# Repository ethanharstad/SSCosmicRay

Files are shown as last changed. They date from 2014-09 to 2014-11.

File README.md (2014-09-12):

SSCosmicRay
===========
[Hackaday Project Log](http://hackaday.io/project/2998-Solid-State-Cosmic-Ray-Detector)

Cosmic ray detectors are a common physics experiment and frequently flown on balloons to measure the change in cosmic ray flux with altitude.
These experiments are typically performed with off the shelf Geiger–Müller tube based detectors. G-M tubes are typically quite expensive and involve high voltages which can become difficult to manage in the near vacuum experienced with high altitude balloons.
A reverse biased photodiode can be used in much the same way as a G-M tube but with lower cost, lower voltage, almost no dead time, and the additional benefit of an output voltage proportional to the radiation energy. 

Inspired by a Maxim [application note](http://www.maximintegrated.com/en/app-notes/index.mvp/id/2236).

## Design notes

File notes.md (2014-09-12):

# VBPW34FAS(R) Specs
- Active Area: 7.5 mm2
- Filter Passband: 775 to 1050 nm
- 3 db Half Angle: 65 deg
- Breakdown Voltage (V_{BR}): 60 V
- Reverse Dark Current (I_{RD}): 2 nA @ V_R = 10 V
- Diode Capacitance (C_D): 16 pF @ V_R = 10 V
- Active Surface Standoff:
	- VBPW34FAS - 0.73 to 0.83 mm
	- VBPW34FASR - >0.57 mm

# Solid Angle Calculation
1. Detector Area: A_D = 7.5 mm2
2. Detector Side Length: s_D = sqrt(A_D) = 2.74 mm
3. Effective Radius = r_E / 2 = 1.37 mm
4. Effective Area = A_E = pi * (r_E)^2 = 5.9 mm2
5. Radius to Detector = 0.5 * t_PCB + h_AE = 0.8 mm + .57 mm = 1.37 mm
6. Hemisphere Area = A_H = 2 * pi * r^2 = 11.79 mm2
7. Solid Half Angle = A_E / A_H = 50%

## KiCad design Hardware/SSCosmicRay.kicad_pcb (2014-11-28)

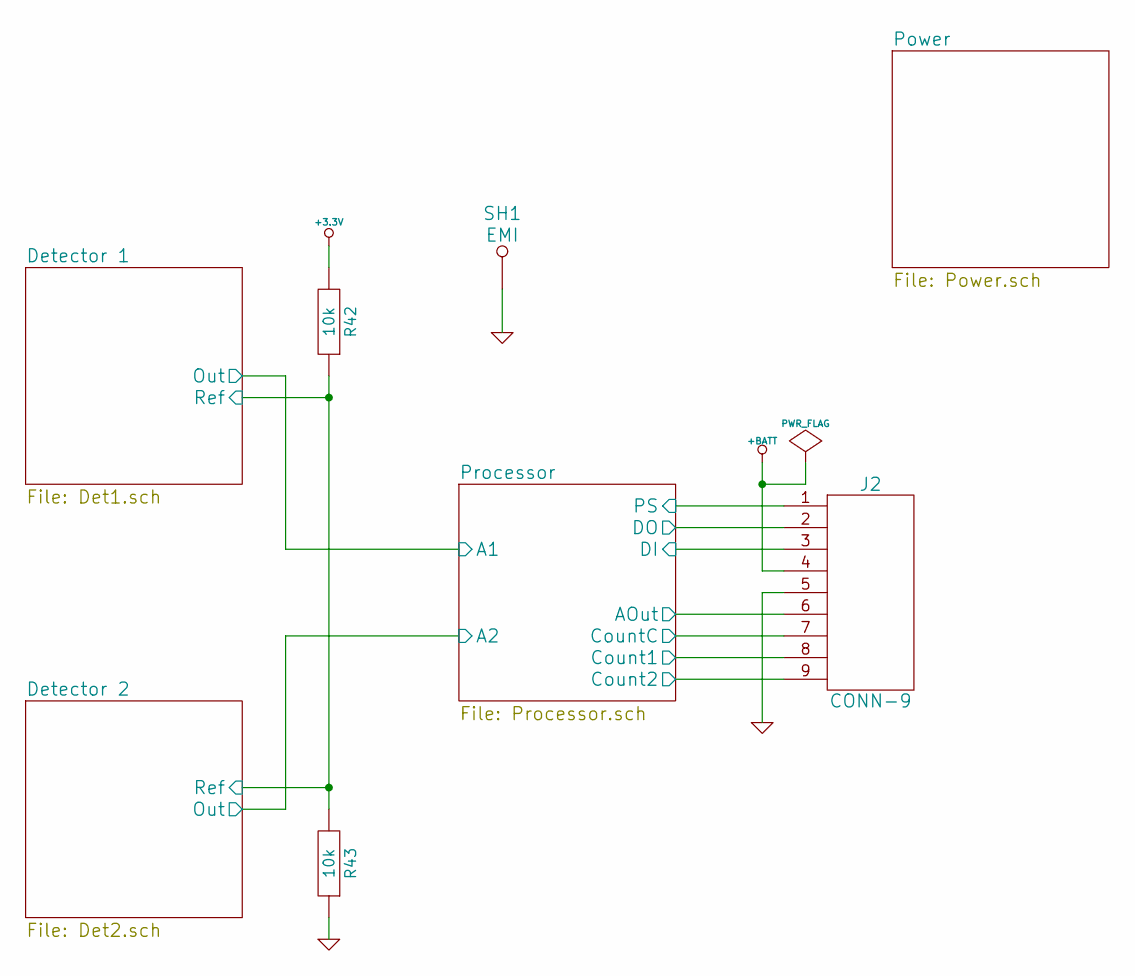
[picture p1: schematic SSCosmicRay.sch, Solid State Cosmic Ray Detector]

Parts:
J2: CONN-9; MFR Part No 1734354-2
R42, R43: 10k; RESC1608; Tolerance 1%; MFR Part No RC0603FR-0710KL
SH1: EMI

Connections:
+3.3V: R42.2; also elsewhere on the board
+BATT: J2.4; also elsewhere on the board
/Detector 1/Ref: R42.1, R43.2; also elsewhere on the board
/Processor/AOut: J2.6; also elsewhere on the board
/Processor/Count1: J2.8; also elsewhere on the board
/Processor/Count2: J2.9; also elsewhere on the board
/Processor/CountC: J2.7; also elsewhere on the board
/Processor/DI: J2.3; also elsewhere on the board
/Processor/DO: J2.2; also elsewhere on the board
/Processor/PS: J2.1; also elsewhere on the board
GND: J2.5, R43.1, SH1.1; also elsewhere on the board

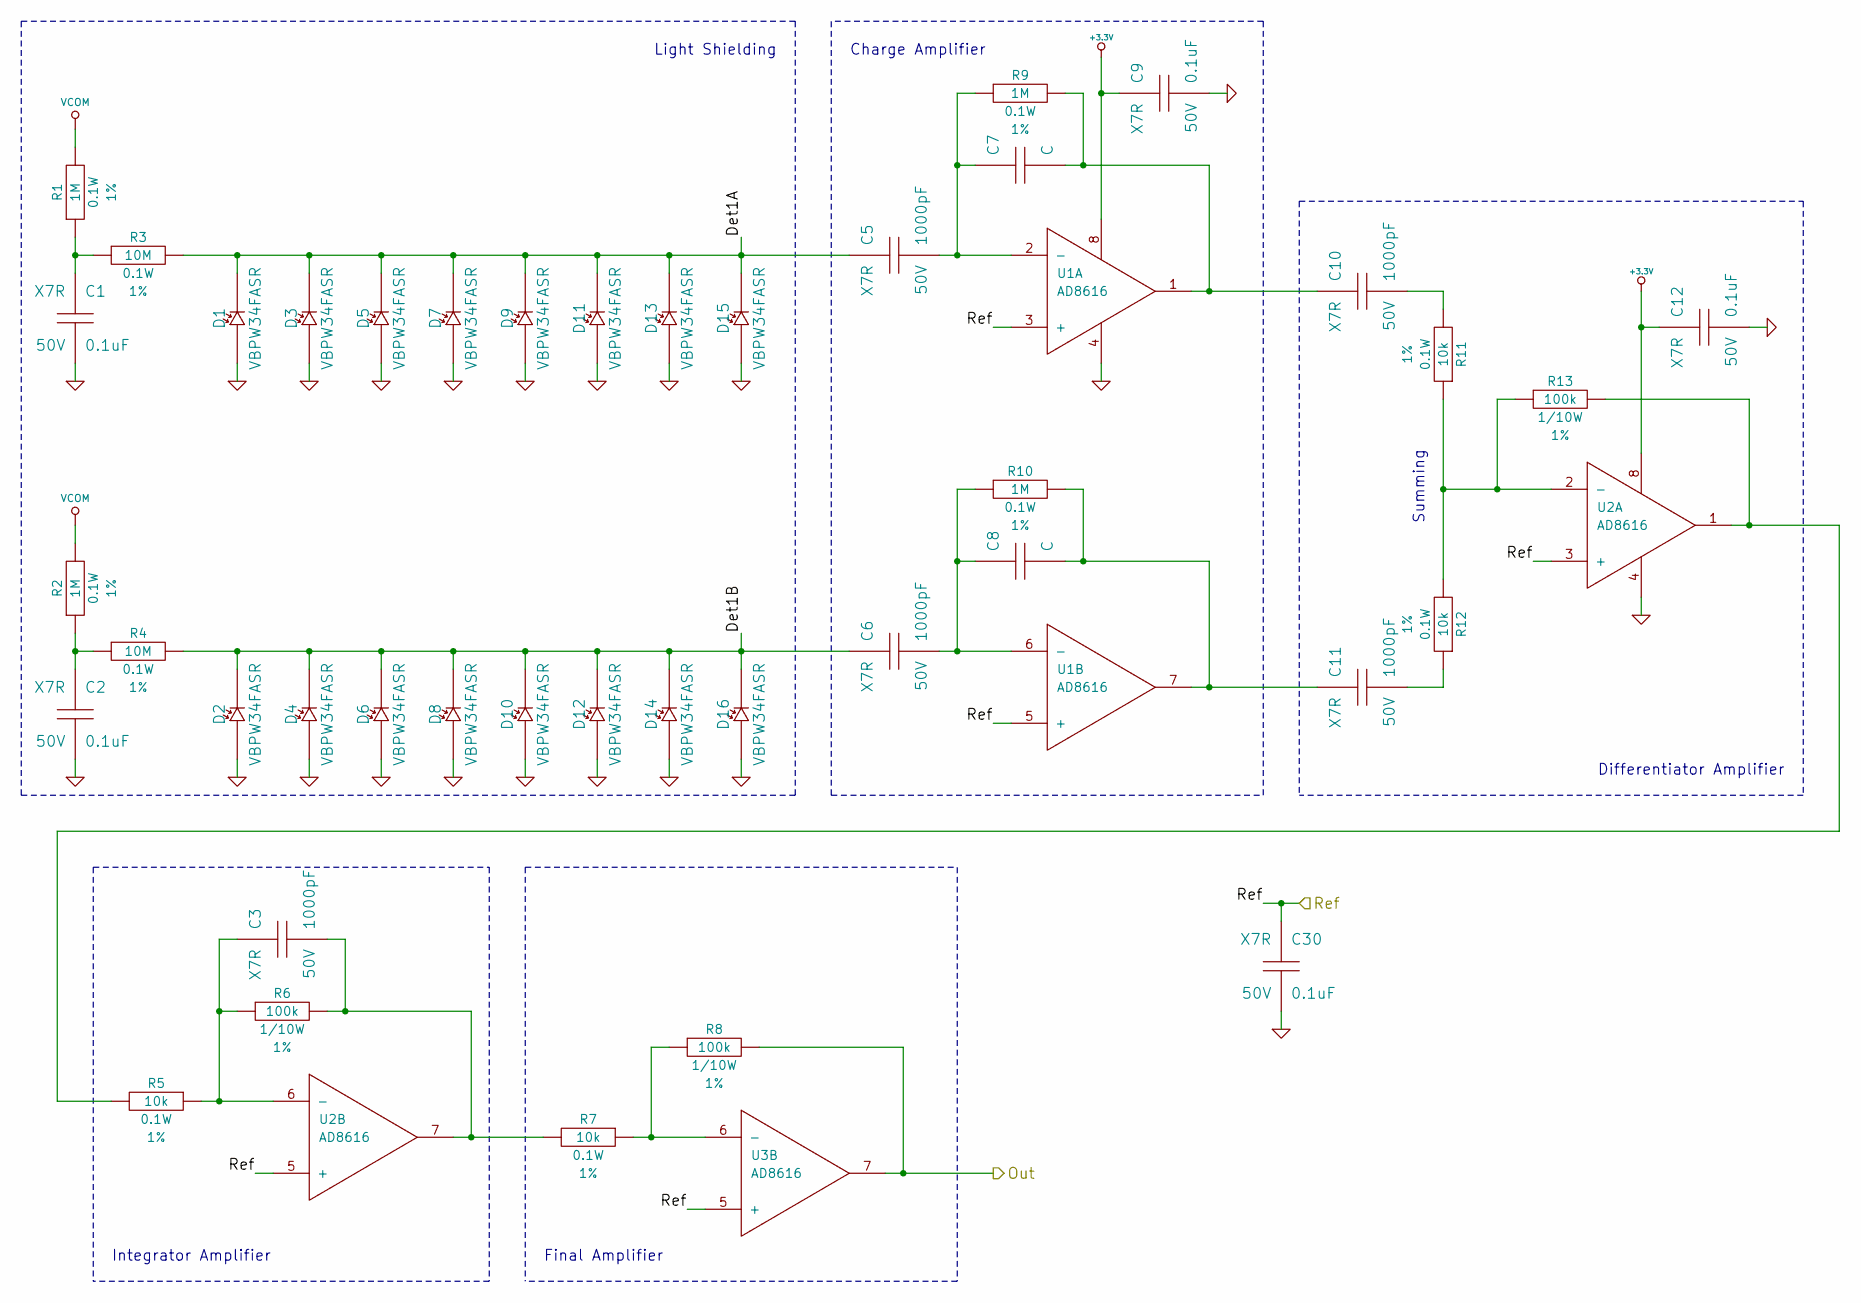
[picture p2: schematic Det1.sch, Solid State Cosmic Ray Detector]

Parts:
C1, C2, C9, C12, C30: 0.1uF; CAPC1608; Voltage 50V; MFR Part No CL10B104KB8SFNC
C3, C5, C6, C10, C11: 1000pF; CAPC1608; Voltage 50V; MFR Part No CL10B102KB8SFNC
C7, C8: C; Voltage V
D1, D2, D3, D4, D5, D6, D7, D8, D9, D10, D11, D12, D13, D14, D15, D16: VBPW34FASR; DIOC-BPW34R; MFR Part No VBPW34FASR
R1, R2, R9, R10: 1M; RESC1608; Tolerance 1%; MFR Part No RC0603FR-071ML
R3, R4: 10M; RESC1608; Tolerance 1%; MFR Part No RC0603FR-0710ML
R5, R7, R11, R12: 10k; RESC1608; Tolerance 1%; MFR Part No RC0603FR-0710KL
R6, R8, R13: 100k; Tolerance 1%; MFR Part No RC0603FR-07100KL
U1, U2, U3: AD8616; MFR Part No AD8616ARMZ-REEL

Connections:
+3.3V: C9.1, C12.1, U1.8, U2.8; also elsewhere on the board
/Detector 1/Det1A: C5.1, D1.2, D3.2, D5.2, D7.2, D9.2, D11.2, D13.2, D15.2, R3.2
/Detector 1/Det1B: C6.1, D2.2, D4.2, D6.2, D8.2, D10.2, D12.2, D14.2, D16.2, R4.2
/Detector 1/Ref: C30.1, U1.3 (+), U1.5 (+), U2.3 (+), U2.5 (+), U3.5 (+); also elsewhere on the board
/Processor/A1: R8.2, U3.7; also elsewhere on the board
GND: C1.2, C2.2, C9.2, C12.2, C30.2, D1.1, D2.1, D3.1, D4.1, D5.1, D6.1, D7.1, D8.1, D9.1, D10.1, D11.1, D12.1, D13.1, D14.1, D15.1, D16.1, U1.4, U2.4; also elsewhere on the board
unnamed: C8.2, C11.1, R10.2, U1.7
unnamed: C11.2, R12.1
unnamed: C10.2, R11.2
unnamed: C3.2, R6.2, R7.2, U2.7
unnamed: C7.2, C10.1, R9.2, U1.1
unnamed: R11.1, R12.2, R13.1, U2.2 (-)
unnamed: R7.1, R8.1, U3.6 (-)
unnamed: C3.1, R5.1, R6.1, U2.6 (-)
unnamed: R5.2, R13.2, U2.1
unnamed: C6.2, C8.1, R10.1, U1.6 (-)
unnamed: C5.2, C7.1, R9.1, U1.2 (-)
unnamed: C2.1, R2.1, R4.1
unnamed: C1.1, R1.1, R3.1
VCOM: R1.2, R2.2; also elsewhere on the board

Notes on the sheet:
Charge Amplifier
Differentiator Amplifier
Integrator Amplifier
Summing
Light Shielding
Final Amplifier

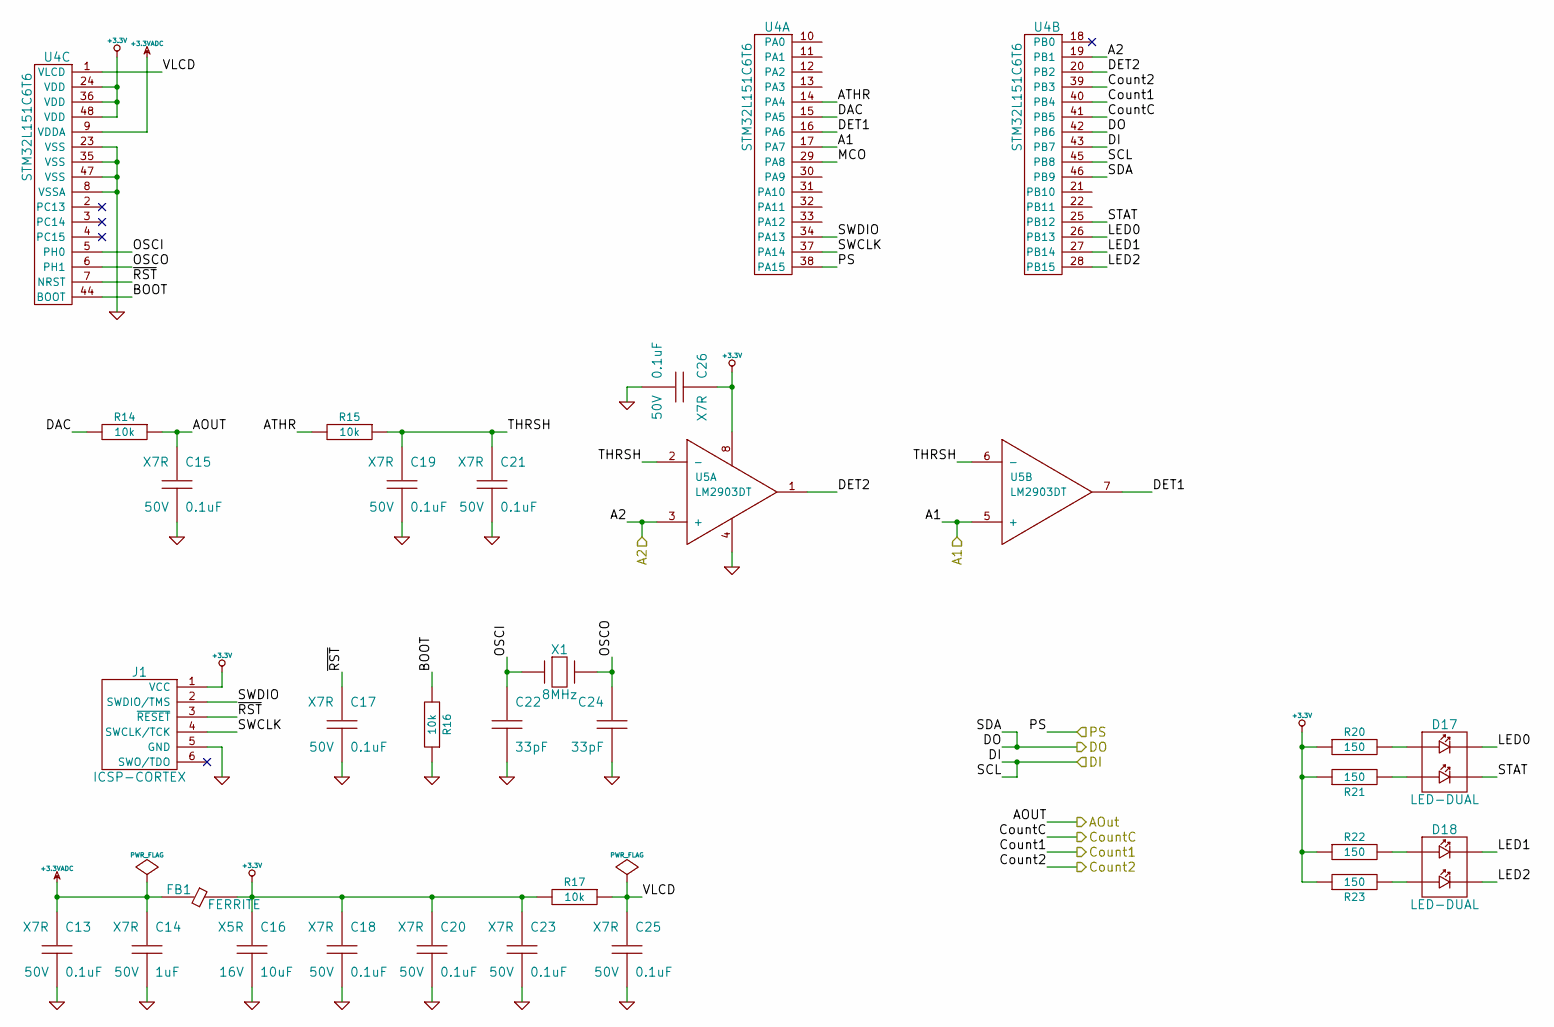
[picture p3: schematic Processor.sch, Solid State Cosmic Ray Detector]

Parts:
C13, C15, C17, C18, C19, C20, C21, C23, C25, C26: 0.1uF; CAPC1608; Voltage 50V; MFR Part No CL10B104KB8SFNC
C14: 1uF; CAPC1608; Voltage 50V; MFR Part No CL21B105KBFNNNE
C16: 10uF; CAPC2012; Voltage 16V; MFR Part No EMK212BJ106KG-T
C22, C24: 33pF; Voltage 50V; MFR Part No C0603C330J5GACTU
D17: LED-DUAL; Voltage V; MFR Part No 553-0121F
D18: LED-DUAL; Voltage V; MFR Part No 553-0122F
FB1: FERRITE
J1: ICSP-CORTEX
R14, R15, R16, R17: 10k; RESC1608; Tolerance 1%; MFR Part No RC0603FR-0710KL
R20, R21, R22, R23: 150; RESC1608; Tolerance %; MFR Part No RMCF0603FT150R
U4: STM32L151C6T6; MFR Part No STM32L151C6T6
U5: LM2903DT; MFR Part No LM2903DGKR
X1: 8MHz; MFR Part No ABM7-8.000MHZ-D2Y-T

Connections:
+3.3V: C16.1, C18.1, C20.1, C23.1, C26.1, FB1.2, J1.1 (VCC), R17.2, R20.1, R21.1, R22.1, R23.1, U4.24 (VDD), U4.36 (VDD), U4.48 (VDD), U5.8; also elsewhere on the board
+3.3VADC: C13.1, C14.1, FB1.1, U4.9 (VDDA)
/Processor/A1: U4.17 (PA7), U5.5 (+); also elsewhere on the board
/Processor/A2: U4.19 (PB1), U5.3 (+); also elsewhere on the board
/Processor/AOut: C15.1, R14.1; also elsewhere on the board
/Processor/ATHR: R15.2, U4.14 (PA4)
/Processor/BOOT: R16.2, U4.44 (BOOT)
/Processor/Count1: U4.40 (PB4); also elsewhere on the board
/Processor/Count2: U4.39 (PB3); also elsewhere on the board
/Processor/CountC: U4.41 (PB5); also elsewhere on the board
/Processor/DAC: R14.2, U4.15 (PA5)
/Processor/DET1: U4.16 (PA6), U5.7
/Processor/DET2: U4.20 (PB2), U5.1
/Processor/DI: U4.43 (PB7), U4.45 (PB8); also elsewhere on the board
/Processor/DO: U4.42 (PB6), U4.46 (PB9); also elsewhere on the board
/Processor/LED0: D17.2, U4.26 (PB13)
/Processor/LED1: D18.2, U4.27 (PB14)
/Processor/LED2: D18.4, U4.28 (PB15)
/Processor/OSCI: C22.1, U4.5 (PH0), X1.1
/Processor/OSCO: C24.1, U4.6 (PH1), X1.2
/Processor/PS: U4.38 (PA15); also elsewhere on the board
/Processor/STAT: D17.4, U4.25 (PB12)
/Processor/SWCLK: J1.4 (SWCLK/TCK), U4.37 (PA14)
/Processor/SWDIO: J1.2 (SWDIO/TMS), U4.34 (PA13)
/Processor/THRSH: C19.1, C21.1, R15.1, U5.2 (-), U5.6 (-)
/Processor/VLCD: C25.1, R17.1, U4.1 (VLCD)
/Processor/~RST: C17.1, J1.3 (~RESET), U4.7 (NRST)
GND: C13.2, C14.2, C15.2, C16.2, C17.2, C18.2, C19.2, C20.2, C21.2, C22.2, C23.2, C24.2, C25.2, C26.2, J1.5 (GND), R16.1, U4.8 (VSSA), U4.23 (VSS), U4.35 (VSS), U4.47 (VSS), U5.4; also elsewhere on the board
unnamed: D18.3, R23.2
unnamed: D18.1, R22.2
unnamed: D17.3, R21.2
unnamed: D17.1, R20.2

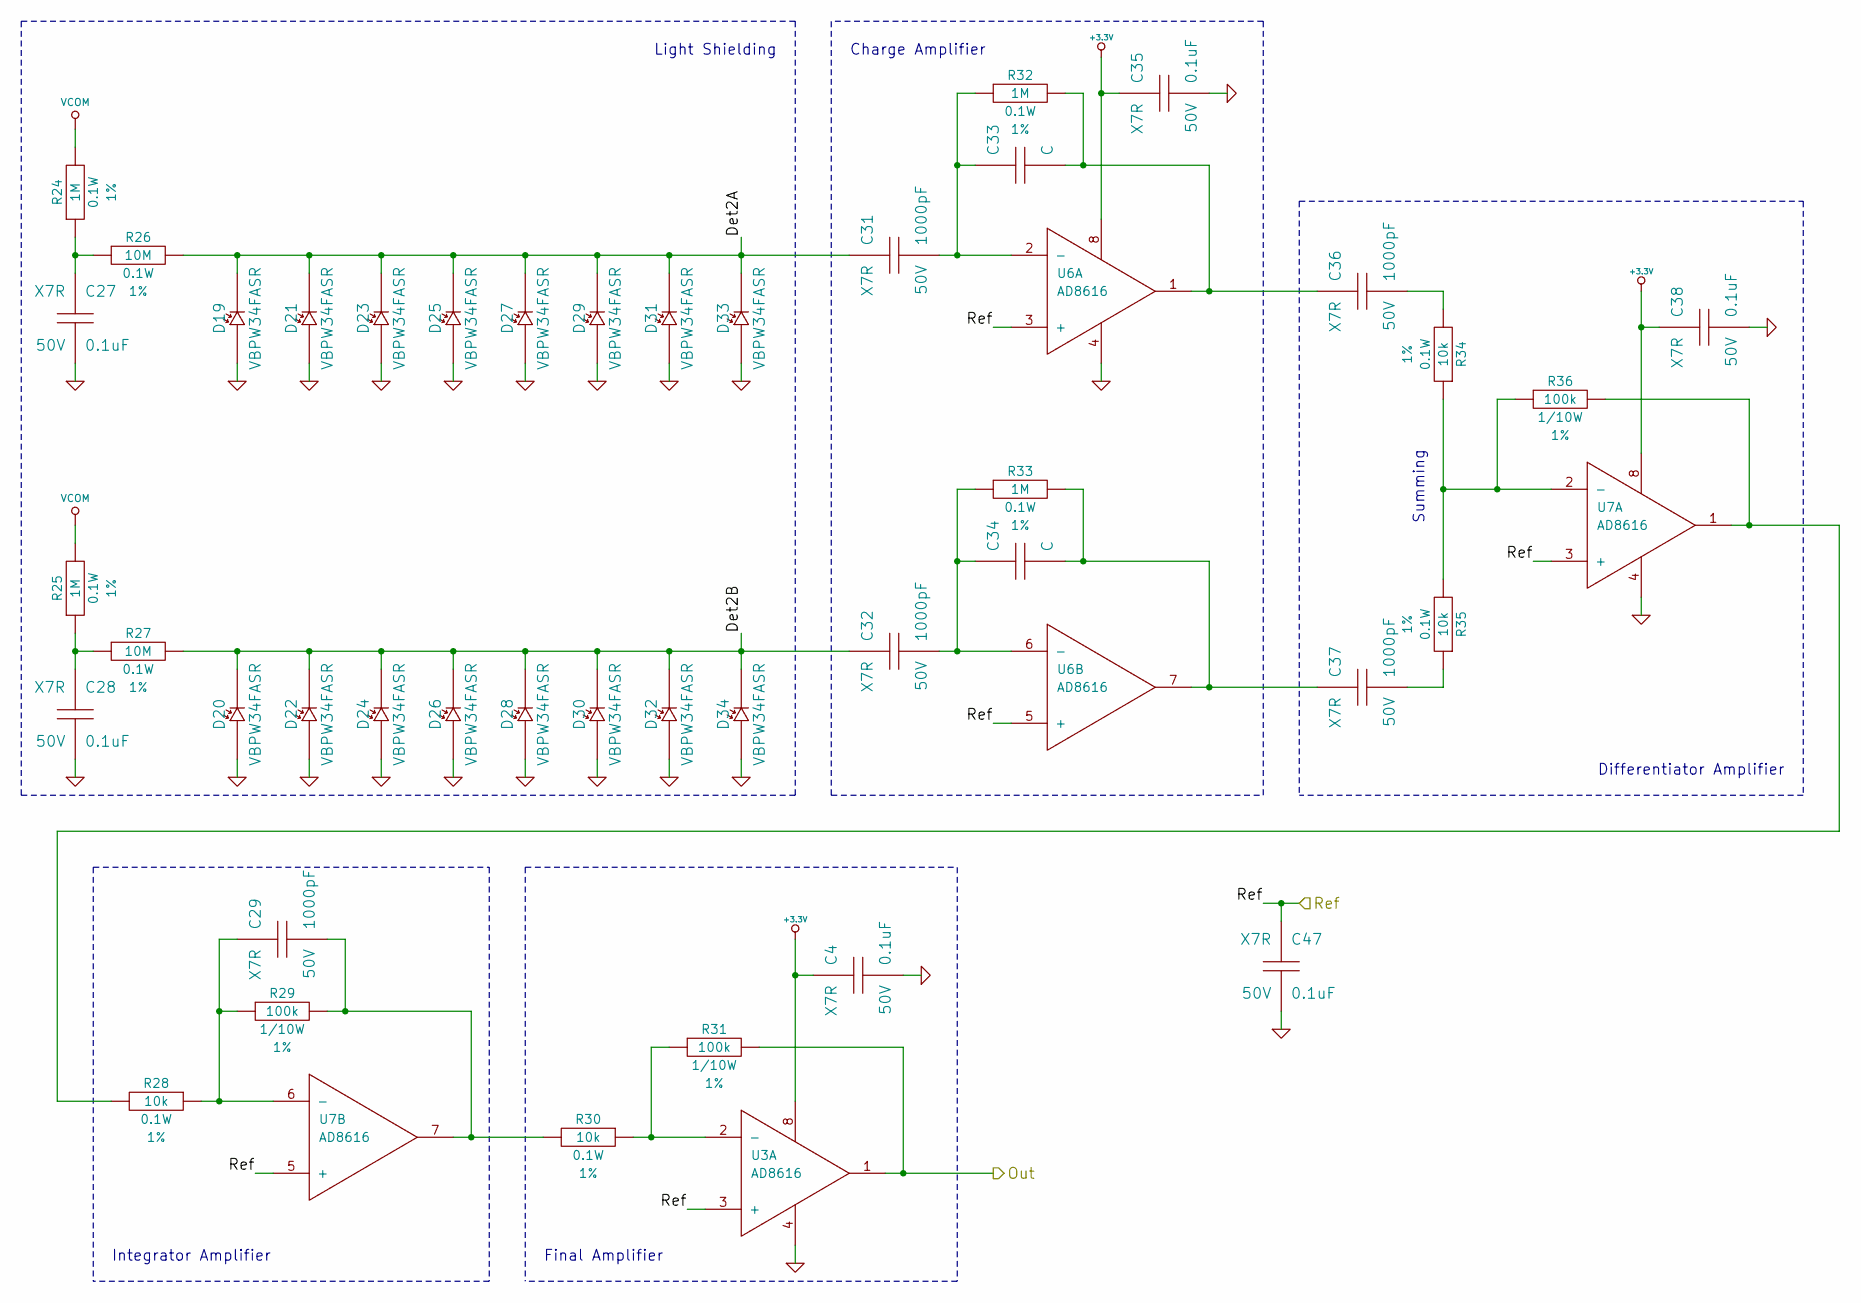
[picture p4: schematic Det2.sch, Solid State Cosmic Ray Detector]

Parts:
C4, C27, C28, C35, C38, C47: 0.1uF; CAPC1608; Voltage 50V; MFR Part No CL10B104KB8SFNC
C29, C31, C32, C36, C37: 1000pF; CAPC1608; Voltage 50V; MFR Part No CL10B102KB8SFNC
C33, C34: C; Voltage V
D19, D20, D21, D22, D23, D24, D25, D26, D27, D28, D29, D30, D31, D32, D33, D34: VBPW34FASR; DIOC-BPW34R; MFR Part No VBPW34FASR
R24, R25, R32, R33: 1M; RESC1608; Tolerance 1%; MFR Part No RC0603FR-071ML
R26, R27: 10M; RESC1608; Tolerance 1%; MFR Part No RC0603FR-0710ML
R28, R30, R34, R35: 10k; RESC1608; Tolerance 1%; MFR Part No RC0603FR-0710KL
R29, R31, R36: 100k; Tolerance 1%; MFR Part No RC0603FR-07100KL
U3, U6, U7: AD8616; MFR Part No AD8616ARMZ-REEL

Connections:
+3.3V: C4.1, C35.1, C38.1, U3.8, U6.8, U7.8; also elsewhere on the board
/Detector 1/Ref: C47.1, U3.3 (+), U6.3 (+), U6.5 (+), U7.3 (+), U7.5 (+); also elsewhere on the board
/Detector 2/Det2A: C31.1, D19.2, D21.2, D23.2, D25.2, D27.2, D29.2, D31.2, D33.2, R26.2
/Detector 2/Det2B: C32.1, D20.2, D22.2, D24.2, D26.2, D28.2, D30.2, D32.2, D34.2, R27.2
/Processor/A2: R31.2, U3.1; also elsewhere on the board
GND: C4.2, C27.2, C28.2, C35.2, C38.2, C47.2, D19.1, D20.1, D21.1, D22.1, D23.1, D24.1, D25.1, D26.1, D27.1, D28.1, D29.1, D30.1, D31.1, D32.1, D33.1, D34.1, U3.4, U6.4, U7.4; also elsewhere on the board
unnamed: C29.1, R28.1, R29.1, U7.6 (-)
unnamed: C37.2, R35.1
unnamed: C29.2, R29.2, R30.2, U7.7
unnamed: C34.2, C37.1, R33.2, U6.7
unnamed: R28.2, R36.2, U7.1
unnamed: C32.2, C34.1, R33.1, U6.6 (-)
unnamed: C36.2, R34.2
unnamed: R34.1, R35.2, R36.1, U7.2 (-)
unnamed: R30.1, R31.1, U3.2 (-)
unnamed: C33.2, C36.1, R32.2, U6.1
unnamed: C31.2, C33.1, R32.1, U6.2 (-)
unnamed: C28.1, R25.1, R27.1
unnamed: C27.1, R24.1, R26.1
VCOM: R24.2, R25.2; also elsewhere on the board

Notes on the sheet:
Charge Amplifier
Differentiator Amplifier
Integrator Amplifier
Summing
Light Shielding
Final Amplifier

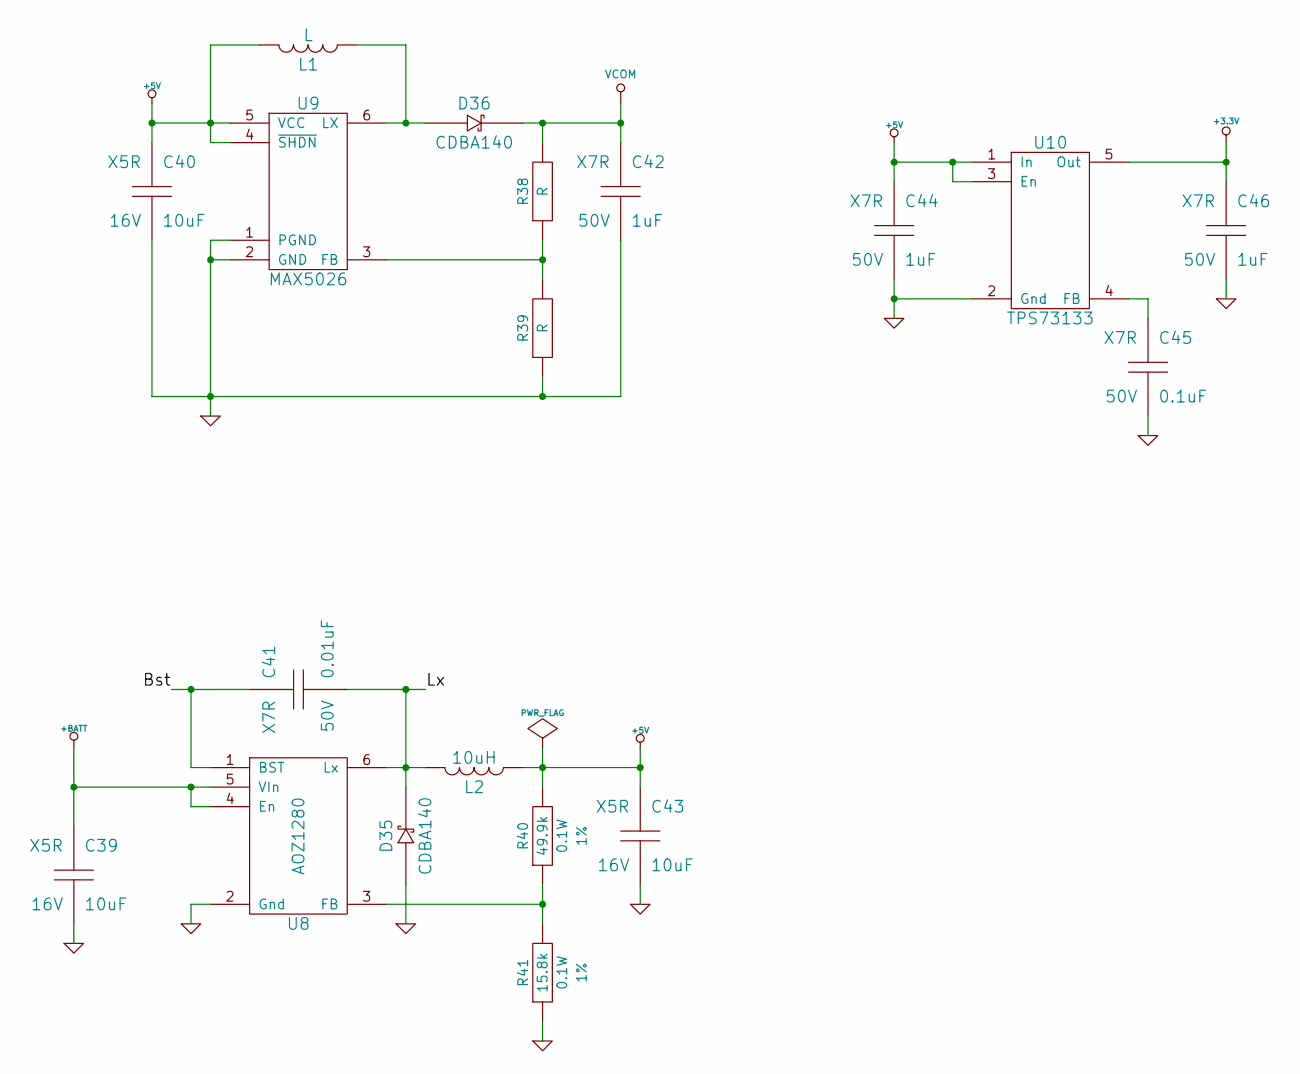
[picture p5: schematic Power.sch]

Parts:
C39, C40, C43: 10uF; Voltage 16V; MFR Part No EMK212BJ106KG-T
C41: 0.01uF; CAPC1608; Voltage 50V; MFR Part No CL10B103KB8NCNC
C42, C44, C46: 1uF; CAPC1608; Voltage 50V; MFR Part No CL21B105KBFNNNE
C45: 0.1uF; CAPC1608; Voltage 50V; MFR Part No CL10B104KB8SFNC
D35, D36: CDBA140; MFR Part No CDBA140-G
L1: L
L2: 10uH; INDC3225; MFR Part No CBC3225T100MR
R38, R39: R; Tolerance %
R40: 49.9k; RESC1608; Tolerance 1%; MFR Part No RC0603FR-0749K9L
R41: 15.8k; RESC1608; Tolerance 1%; MFR Part No RC0603FR-0715K8L
U8: AOZ1280; MFR Part No AOZ1280CI
U9: MAX5026; MFR Part No MAX5026EUT+T
U10: TPS73133; MFR Part No TPS73133DBVR

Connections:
+3.3V: C46.1, U10.5 (Out); also elsewhere on the board
+5V: C40.1, C43.1, C44.1, L1.1, L2.2, R40.2, U9.4 (~SHDN), U9.5 (VCC), U10.1 (In), U10.3 (En)
+BATT: C39.1, U8.4 (En), U8.5 (VIn); also elsewhere on the board
/Power/Bst: C41.1, U8.1 (BST)
/Power/Lx: C41.2, D35.2, L2.1, U8.6 (Lx)
GND: C39.2, C40.2, C42.2, C43.2, C44.2, C45.2, C46.2, D35.1, R39.1, R41.1, U8.2 (Gnd), U9.1 (PGND), U9.2 (GND), U10.2 (Gnd); also elsewhere on the board
unnamed: C45.1, U10.4 (FB)
unnamed: R38.1, R39.2, U9.3 (FB)
unnamed: R40.1, R41.2, U8.3 (FB)
unnamed: D36.1, L1.2, U9.6 (LX)
VCOM: C42.1, D36.2, R38.2; also elsewhere on the board

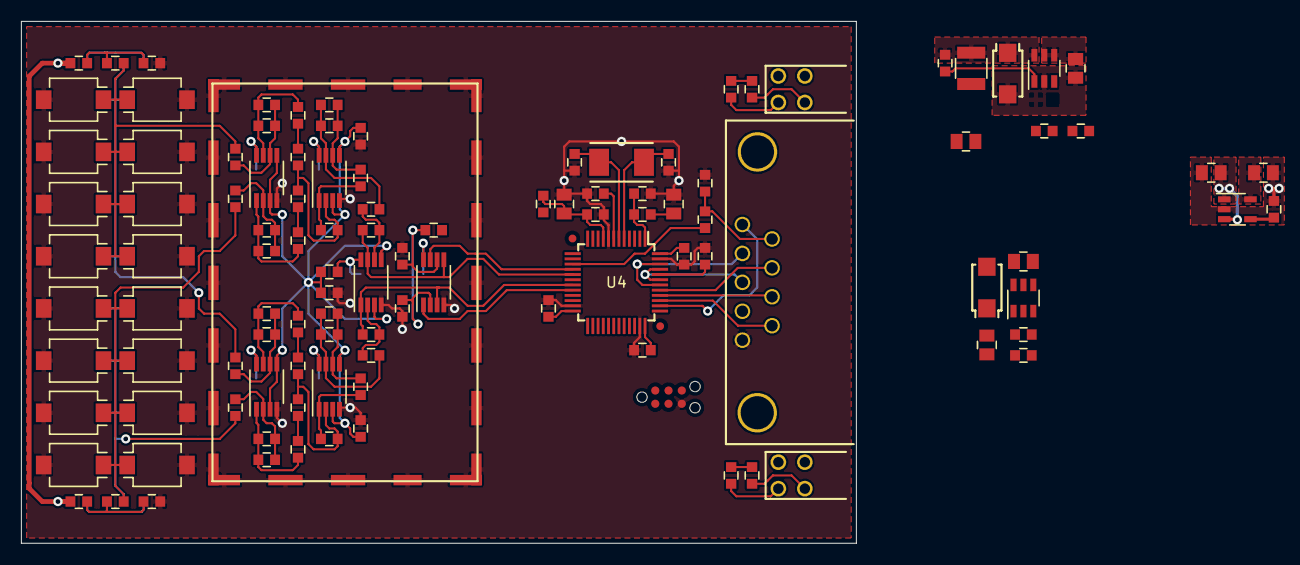
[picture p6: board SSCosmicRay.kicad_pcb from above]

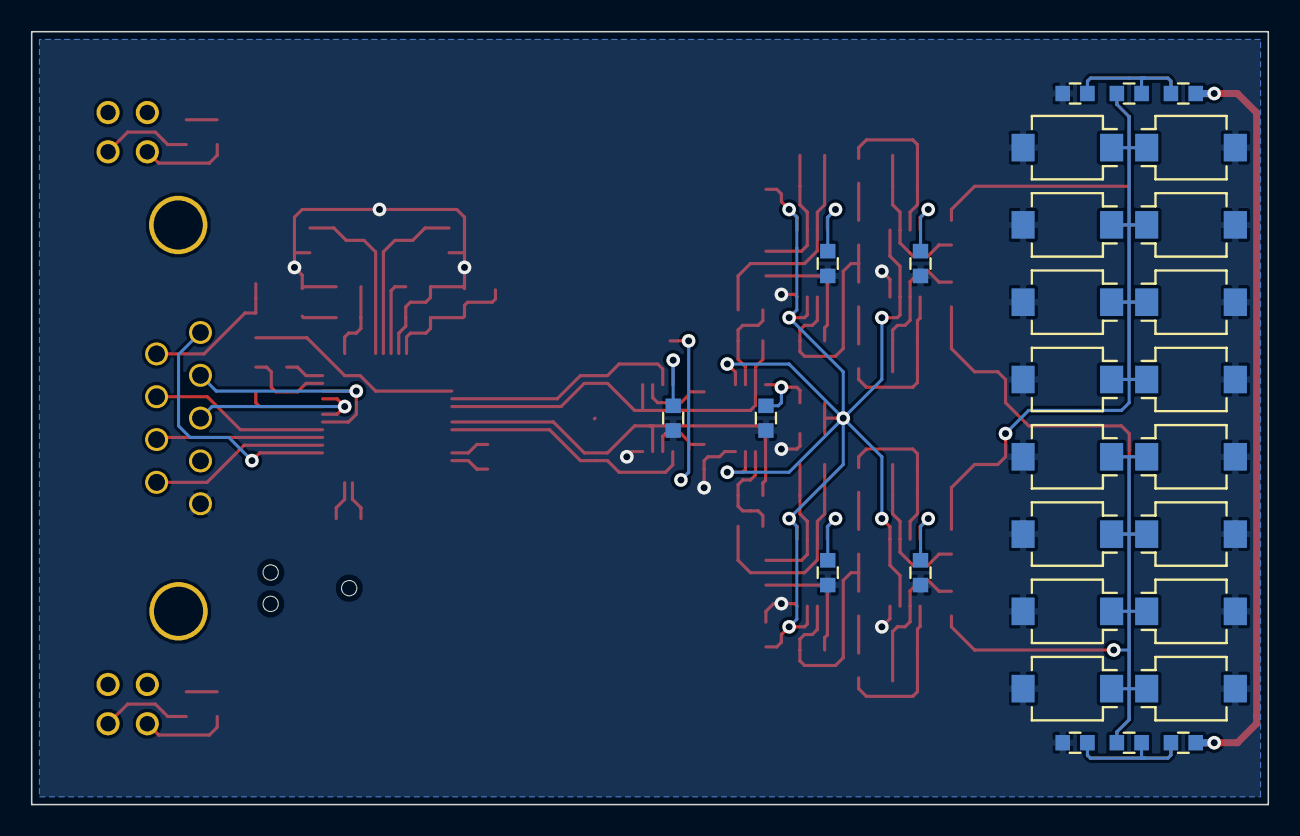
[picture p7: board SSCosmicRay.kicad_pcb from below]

Board: 2 copper layers, 80.0 x 50.0 mm, 139 parts (28 on the bottom side), 72 nets.

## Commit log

2013-09-20 Add amplifier signal chain
    [SSCosmicRay.sch]
2013-09-21 Switch to hierarchical schematic, add detector section
    [Amp1.sch, Det1.sch, SSCosmicRay.sch]
2013-09-23 Add detector and coincidence sections
    [Amp1.sch, Coincedence.sch, Det1.sch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]
2013-09-24 Add processor section
    [Processor.sch, SSCosmicRay.sch]
2013-09-24 Add processor support circuitry
    [Amp1.sch, Coincedence.sch, Det1.sch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]
2013-09-24 Fill BOM fields of amplifier section
    [$Amp1.sch, $Det1.sch, Processor.sch]
2013-09-24 Fill BOM fields for detector section
    [$Amp1.sch, $Det1.sch, Amp1.sch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]
2013-09-24 Fill BOM fields for coincidence section
    [Coincedence.sch]
2013-09-24 Add second detection chain
    [Amp2.sch, Coincedence.sch, Det1.sch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]
2013-09-24 Initial annotation
    [Amp1.sch, Amp2.sch, Coincedence.sch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]
2013-09-24 Initial component mapping
    [Amp1.sch, Amp2.sch, Coincedence.sch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]
2013-09-24 Map test points
    [Amp1.sch, Amp2.sch]
2013-09-24 Fix pinout problem on potentiometer
    [Coincedence.sch, SSCosmicRay.sch]
2013-09-24 Switch analog chain to 3.3v supply
    [Power.sch]
2013-09-24 Update gitignore for kicad temp files
2013-09-26 Add power section. Switch to smaller pot
    [Amp1.sch, Amp2.sch, Coincedence.sch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]
2013-09-26 Associate switches
    [Amp1.sch, Amp2.sch, Coincedence.sch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]
2013-09-27 Add 12v regulator and populate BOM fields
    [Amp1.sch, Amp2.sch, Coincedence.sch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]
2013-09-27 Add 3.3v regulator and populate BOM fields
    [Power.sch]
2013-12-06 Refresh footprints to IPC compliant versions
    [SSCosmicRay.kicad_pcb]
2013-12-07 Reroute signal chain with IPC spacing
    [SSCosmicRay.kicad_pcb]
2013-12-08 Power sections
    [SSCosmicRay.kicad_pcb]
2013-12-08 Switch to larger enclosure
    [SSCosmicRay.kicad_pcb]
2013-12-19 Fully route signal chain
    [SSCosmicRay.kicad_pcb]
2013-12-21 Switch to 44 pin PIC
    [Amp1.sch, Amp2.sch, Coincedence.sch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]
2013-12-21 Add external connector
    [Amp1.sch, Amp2.sch, Coincedence.sch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]
2013-12-21 Change bias supply to reference layout
    [SSCosmicRay.kicad_pcb]
2013-12-22 Change to vertical USB port
    [Amp1.sch, Amp2.sch, Coincedence.sch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]
2013-12-22 Add additional photodiodes
    [Amp1.sch, Amp2.sch, Coincedence.sch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]
2013-12-22 Add status LEDs
    [Amp2.sch, Det2.sch, Power.sch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]
2013-12-24 Connect LEDs
    [Processor.sch, SSCosmicRay.kicad_pcb]
2013-12-24 Remove coincidence circuitry
    PIC32 internal comparator has sufficient performance
    [Amp1.sch, Amp2.sch, Coincedence.sch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]
2013-12-24 Move amplifiers into detection subsheets
    Reannotate
    [Amp1.sch, Amp2.sch, Det1.sch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]
2013-12-26 New signal chain layout
    [Det1.sch, Det2.sch, Power.sch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]
2013-12-27 Add shielding fingers to bottom of board
    [Det1.sch, Det2.sch, Power.sch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]
2014-01-04 Additional layout
    [Det1.sch, Det2.sch, Power.sch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]
2014-09-07 Remove old processor
    Supports #1
    [SSCosmicRay.kicad_pcb]
2014-09-07 Remove extra circuitry
    [Processor.sch]
2014-09-07 Update components
    [Det2.sch, Power.sch, Processor.sch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]
2014-09-11 Processor support circuitry
    [Det1.sch, Det2.sch, Power.sch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]
2014-09-11 Component associations
    [Det2.sch, Power.sch, Processor.sch]
2014-09-11 Rough layout processor support components
    [SSCosmicRay.kicad_pcb]
2014-09-11 Add threshold detector
    [Det2.sch, Power.sch, Processor.sch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]
2014-09-11 Change DB9 to in stock part
    [Processor.sch]
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2014-09-11 Serial IO connections
    [Det2.sch, Power.sch, Processor.sch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]
2014-09-11 EDRC checking
    [Det2.sch, Power.sch, Processor.sch]
2014-09-11 Change output pinout
    [Processor.sch, SSCosmicRay.kicad_pcb]
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2014-09-12 Replace comparator with SSOP version
    Closes #3
    [Det1.sch, Det2.sch, Power.sch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]
2014-09-22 Replace boost converter
    Closes #4
    [Det1.sch, Det2.sch, Power.sch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]
2014-09-22 Clear board, associations and annotations
    Prepare for new topology
    [SSCosmicRay.kicad_pcb]
2014-09-22 Clear annotations
    [Det1.sch, Det2.sch, Power.sch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]
2014-09-23 Add LDO for analog
    [Det1.sch, Det2.sch, Power.sch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]
2014-09-23 New detector chain
    [Det1.sch, Det2.sch]
2014-09-23 Rearrange detector chain
    [Det1.sch, Power.sch, Processor.sch]
2014-09-24 Component values
    [Det1.sch, Det2.sch, Power.sch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]
2014-09-24 Add second detector chain
    [Det2.sch]
2014-09-25 Change to STM32L151C
    Closes #7
    [Det1.sch, Det2.sch, Power.sch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]
2014-09-25 Swap to higher voltage 1u cap
    [Power.sch, Processor.sch]
2014-09-28 Rough layout for pin map testing
    [Det1.sch, Det2.sch, Power.sch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]
2014-09-29 Add opamp reference voltage
    [Det1.sch, Det2.sch, Power.sch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]
2014-09-29 Change comparator label for better routing
    [Det1.sch, Det2.sch, Power.sch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]
2014-09-29 Equalize feedback network spacing
    [Processor.sch, SSCosmicRay.kicad_pcb]
2014-09-29 Move interface connector to root sheet
    [Det1.sch, Processor.sch, SSCosmicRay.kicad_pcb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]
2014-10-29 Input voltage preregulation to extend input range
    Closes #8
    [Det1.sch, Det2.sch, Power.sch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]
2014-11-02 Connect interface pins
    [Det1.sch, Det2.sch, Power.sch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]
2014-11-03 Route 3v3 regulator
    [SSCosmicRay.kicad_pcb]
2014-11-18 Remove discrete pull-ups in favor of on chip pull-ups
    [Det1.sch, Det2.sch, Power.sch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]
2014-11-28 Remove unneeded pullup on regulator enable
    [Power.sch, SSCosmicRay.kicad_pcb]
